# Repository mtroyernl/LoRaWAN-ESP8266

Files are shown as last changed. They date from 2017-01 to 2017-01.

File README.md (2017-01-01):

# LoRaWAN-ESP8266

Created by Mark Troyer  -  31 December 2016

Inspired by original code from Thomas Telkamp and Matthijs Kooijman  https://github.com/matthijskooijman/arduino-lmic/

## Introduction
This respository explains how to get started with LoRaWAN and The Things Network at a cost of under $50 using readily available parts.   The build consists of a LoRaWAN gateway and a simple node that senses temperature, humidity and light levels using The Things Network (thethingsnetwork.org) crowdfunded infrastructure.

The primary benefits of this build are as follows:

- Creation of an end-to-end applicaiton that leverages LoRaWAN technology and The Things Network infrastructure.
- A Bill of Materials of less that $50 for both a single-channel gateway and a node that senses temperature, humidity and light levels.
- An ideal starting point for hobbyists and professionals seeking to learn more about LoRaWAN and The Things Network.
- Uses the ESP8266 WiFi SoC (System on Chip) for primary microprocessor functions.
- Uses the Arduino IDE for simplified implementation.

In order to build the necessary two  devices, some basic soldering skills are required.  The total build time is around 3 hours.

### Limitations
*This project is built using a single channel LoRaWAN gateway. Strictly-speaking, this is out-of-spec.  LoRaWAN specifications require at minimum 3 channels.   In order to use a single channel gateway, all nodes must include software modifications to limit usage of the same single channel as the gateway.  If tested with other LoRaWAN devices, it may be that only limited packets are received by the single -channel gateway.*   

As the pricing of LoRaWAN 8 channel gateways continues to fall in 2017, it is recommended to NOT use this type of implementation in the longer term.  For basic learning and demostrations, this configuraiton may prove to be helpful to further promote the benefits of LoRaWAN in general and The Things Network specifically.  For any form of a POC (Proof of concept), a proper 8 channel gateway should be used.

## Finished Product
There are two recommended ways to build these devices:  As enclosed devices or as WeMOS D1 Mini stacks.  Building enclosed devices has the benefit of ruggedness for transportation and demonstrations.  For those looking for a rapid prototyping environment, a WeMos D1 Mini stack build is recommended.  Custom shields can be quickly created and tested using a modular hardware approach.  

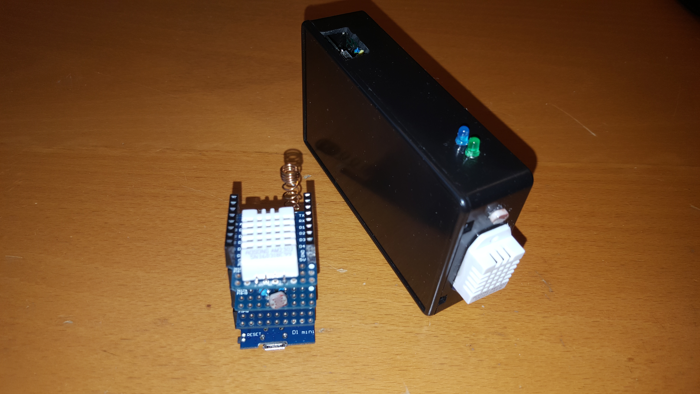
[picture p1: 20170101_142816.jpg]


Below are the internals of an enclosed device used for regular demonstrations.  A simple project box and a prototyping breadboard allow for easy and quick assembly.   Hot glue always helps as well to keep things in place!



The WeMos D1 Mini Stack device offers the ability to quickly test new hardware concepts through the use of a breadboard or custom mini shields.  Seperate shields can me mixed and matched for different experiements. 

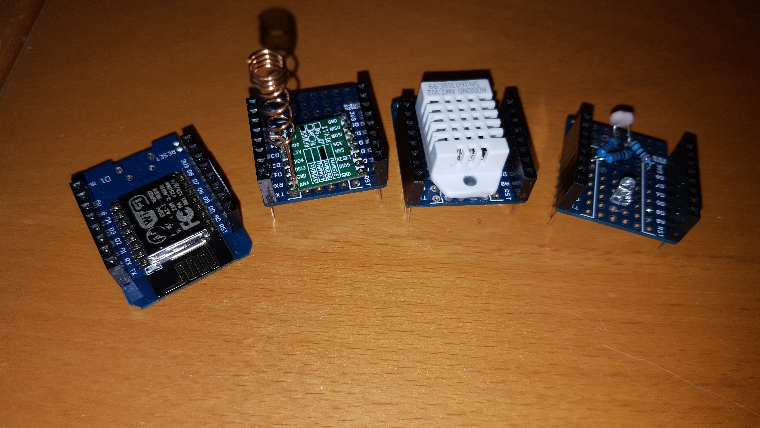
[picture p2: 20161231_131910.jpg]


## Bill of Materials
All of the parts for these builds can be ordered through local electronics suppliers or directly though Chinese suppliers with Ebay, AliExpress or others.  Below is a Bill of Materials suggested for this project:

- Wemos D1 Mini (ESP8266) $3-5 - It is recommended to order 4 or 5 of these devices for all micro processor projects.  Even for devices that do not required WiFi, the ESP8266 price point can not be beaten. The ESP8266 is also significantly faster than most Arduino boards but has fewer IO ports.
- Wemos D1 Mini Shields $2 - Order at least 10 of these for prototyping if you want to go this route.
- Prototyping breadboard $0.40 - Search for "double side prototype pcb tinned universal breadboard 5x7cm".  These are ideal and low cost prototyping breadboards for any project built in a small box.  
- RFM95 at 868MHz $9-12 - This is the basic LoRa module with a Semtech tranciever chip.  Be sure to get the version appropriate for your region (e.g. 868MHz for Europe, 915MHz for North America and Australia).  If you are in Europe, google "ebay RFM95 868" to see what's available.  Note that modules come pre-installed with the appropriate firmware for each frequency region.   Double check that you are ordering the appropriate product for your region.  It is best to order at least 3 in case one arrives DOA (Dead on Arrival) or you *fry* one accidently.
- DHT22 Temperature/Humidity Sensor $4 - Order at least 2-3 of these.
- Light-Dependent Resistor $0.50 - Normaly these come in lots of 20 or more.
- Resistors: 10K, 4K7, 2K2, 1K -  It is best to order an assortment of thru-hole resistors if you do not already have them on hand.
- 8.2cm wire antenna - I used a coil copper antenna tuned for 868MHz.  Alternatively, an 8.2cm piece of wire will also work fine.

## Hardware Schematic
The hardware schematic for the build is below.   All pins on the ESP8266 except D3/GPIO 0 are used.   9 of the 16 pins on the RFM95 are used.  Ignore the references to the RFM69 and 96.   There is still learning to be done with E-CAD !

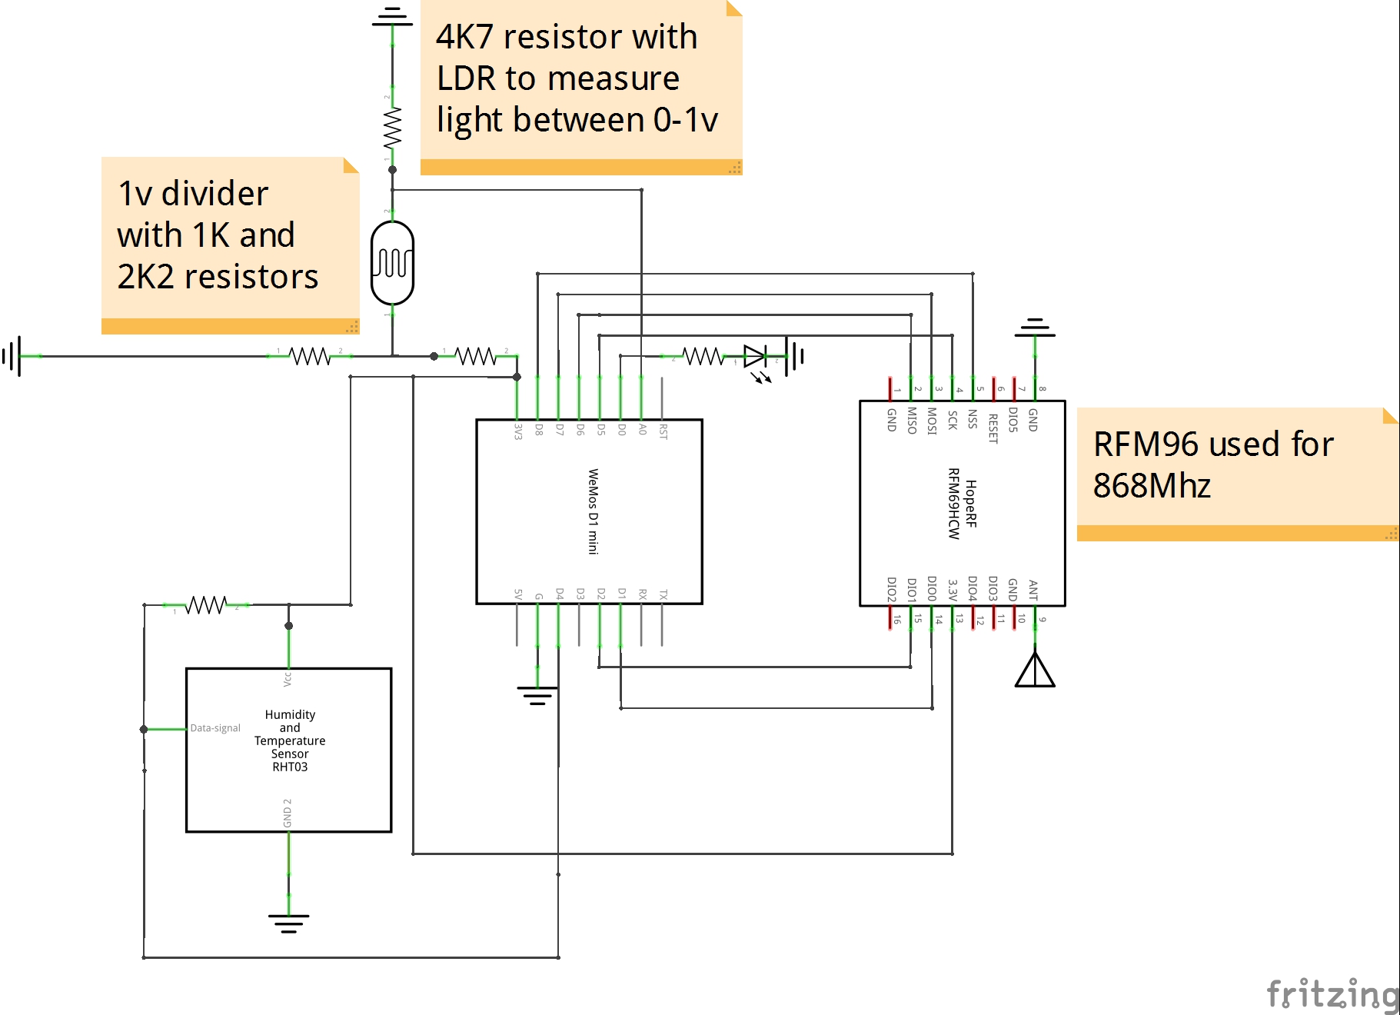
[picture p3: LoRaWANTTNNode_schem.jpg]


## Hardware build

If you are building the device using a WeMos D1 Mini stack design, it is recommended to create 3 seperate shields as follows:

- Shield for DHT22 Temperature/Humidity sensor.  These can also be purchased as finished shields or you can build your own.   If you build your own, it is important to us D4 (GPIO 02) for the signal with a 10K resistor pulled to 3.3v.   Note that D4/GPIO 02 on an ESP8266 should normally always be pulled high for normal and programming operation.   Therefore D4/GPIO 02 is the optimal pin to use for the DHT22.
- Shield for LED light and LDR.   The LED should be connected to D0 and ground.  It is very useful to have an addressable LED in firmware to indicate status of sending/receiving packets.  As the single ADC port on the ESP8266 only works between 0v and 1v, a voltage divider needs to be built using 2K2 (3.3v) and 1K (GND) resistors.  With the LDR (1v) and a 4K7 (GND) in place, a good range of digitally values between 0 and 512 will result.
- Shield for the RFM95.  This is the most complicated part of the build.  There are 9 pins on the RFM95 tranciever module that are required.  Unfortunaely, the pin holes on the RFM95 are 2mm apart where as typical prototyping breadboards are 2.54mm apart.  The result of this is that flexible core copper wire must be used to make the necessary connections to a prototyping breadboard or a header.  While not complex, assembly requires patients and forethought in terms of connections.  

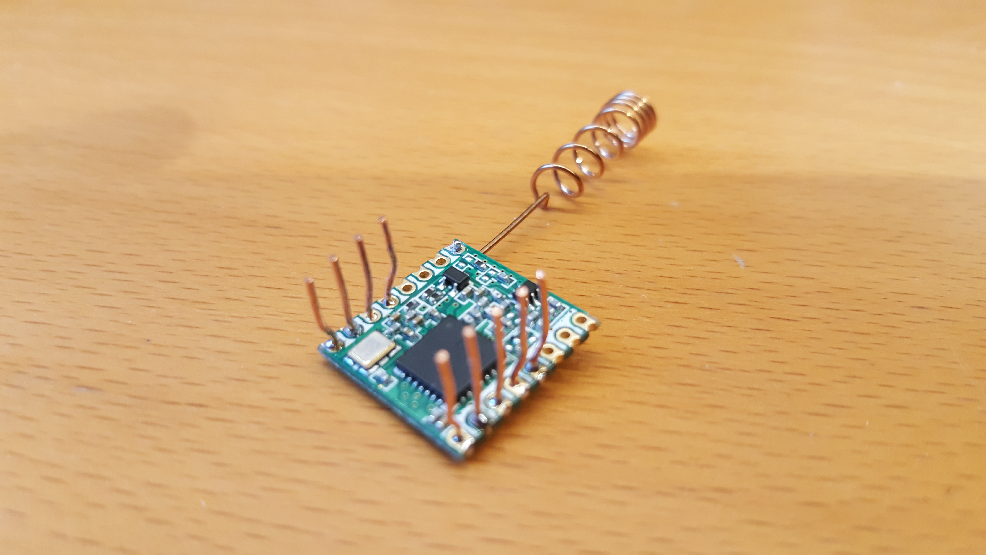
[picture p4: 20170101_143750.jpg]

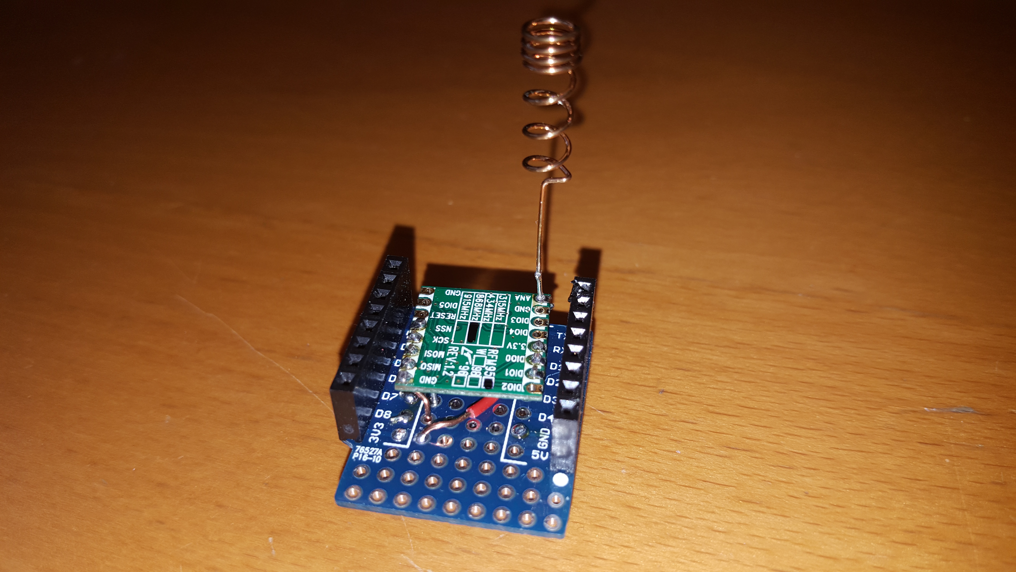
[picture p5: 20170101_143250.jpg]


Building enclosed devices can also be tricky.  Be sure to take your time and think through how connections will be made before soldering.   It is recommended to prototype assemblies first with light single solder junctions or even a bit of hot glue to make sure all will fit together.  Desolding makes a mess!   You may need that extra RFM95 or WeMos board if you did not take the necessary time to plan your build.

## Software for Node build

There will be two software builds available for nodes.  Currently only the ABP version is available.  The first works with ABP (Authentication by Personalization) using statically generated keys.   The second and recommended build works with OTAA (Over the Air Activation).  

Note that constant work is being done on the https://github.com/matthijskooijman/arduino-lmic libraries and example code.   Over time, it may make more sense to retrofit some of the sensor code back into these libraries and examples.

## Software for single-channel LoRaWAN gateway build

Code for a single channel gateway can be found at https://github.com/things4u/ESP-1ch-Gateway-v3.0.   Please be sure to re-read the Limitations section at the beginning of this document.

Note that the hardware build in this example assumes the following mappings.
```
const lmic_pinmap lmic_pins = {
    .nss = 15, // D8
    .rxtx = LMIC_UNUSED_PIN,
    .rst = LMIC_UNUSED_PIN,
    .dio = {4, 5, LMIC_UNUSED_PIN},  // D1, D2
};
```

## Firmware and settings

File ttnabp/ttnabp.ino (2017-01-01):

/*
 *  The Things Network LoRaWAN test object built for under $15.  Takes temperature, humidity, and 
 *  light sensor data and sends to the Things Network (LoRaWAN).
 *  
 *  This particular version was built to work with ABP using a single channel (868.1 mHZ) for use 
 *  with a single channel gateway for demonstrations where TTN network access may not be publically available.  
 *  8 channel functionality can be enabled in code.
 *  
 *  This was insipred from code written by Thomas Telkamp and Matthijs Kooijman  https://github.com/matthijskooijman/arduino-lmic/
 */

#include <lmic.h>           // Download from https://github.com/matthijskooijman/arduino-lmic/
#include <hal/hal.h>        // Download from https://github.com/matthijskooijman/arduino-lmic/
#include <SPI.h>
#include <ESP8266WiFi.h>
#include <DHT.h>

// ESP8266 PIN USAGE
#define LED	D0 // GPIO 16 
#define DIO0	D1 // GPIO 05
#define DIO1	D2 // GPIO 04
#define NC	D3 // GPIO 00 Reserved - Pull high to boot from SPI Flash, low to program via UART
#define DHTPIN D4 // GPIO 02 Reserved - Pulled high.   Matches as input for DHT22
#define SCK   D5 // GPIO 14
#define	MISO	D6 // GPIO 12
#define MOSI	D7 // GPIO 13
#define NSS   D8 // GPIO 15 Reserved - Pulled low to boot from SPI Flash or UART

#define DHTTYPE DHT22
DHT dht(DHTPIN, DHTTYPE, 11); // 11 works fine for ESP8266
float humidity, temperature;
int light, motion;

// LoRaWAN, DevAddr, NwkSKey, AppSKey  - Use ABP Authentication to define the values required for operation.
// See http://thethingsnetwork.org/wiki/AddressSpace
// DevAddr - Logical address created during a session.  This is not the DEV EUI which is normally a MAC layer unique address.  
//           Many LoRa radio chip implementations (e.g. RFM9X) do not have a fixed DEV EUI.
// NwkSKey - Unique shared key created by the APB registration process for the notion of a session.   This is a static key using ABP.
// AppSKey - Unique shared key created by the APB registration process for a given application.   This is a static key using ABP.

static const u4_t DEVADDR = 0x026011361;
static const PROGMEM u1_t NWKSKEY[16] = { 0x8E, 0xB0, 0x83, 0x64, 0x29, 0xBF, 0xEE, 0xFB, 0xBB, 0x3F, 0xF2, 0xBD, 0x25, 0x9F, 0xE6, 0x55 };
static const u1_t PROGMEM APPSKEY[16] = { 0x02, 0x5E, 0xA2, 0x8A, 0xBD, 0xC8, 0x45, 0xA1, 0x3D, 0x20, 0x20, 0x1E, 0x0F, 0x7F, 0xD5, 0x47 };

// These callbacks are only used in over-the-air activation, so they are
// left empty here (we cannot leave them out completely unless
// DISABLE_JOIN is set in config.h, otherwise the linker will complain).
void os_getArtEui (u1_t* buf) { }
void os_getDevEui (u1_t* buf) { }
void os_getDevKey (u1_t* buf) { }

static osjob_t sendjob;

// Schedule TX every this many seconds (might become longer due to duty
// cycle limitations).
const unsigned TX_INTERVAL = 60;

// These PIN assignments need to be adjusted for available pins on the ESP8266.  Using D8, D1, D2 works fine.
const lmic_pinmap lmic_pins = {
    .nss = 15, // D8
    .rxtx = LMIC_UNUSED_PIN,
    .rst = LMIC_UNUSED_PIN,
    .dio = {4, 5, LMIC_UNUSED_PIN},  // D1, D2
};

void blinkn (int i, int pin ) {
  int j;
  for (j=0; j < i; j++) {
    digitalWrite(pin, HIGH);
    delay (200);
    digitalWrite(pin, LOW);
    delay (200); 
  } 
}

void getReadings() {
    humidity = dht.readHumidity();
    yield();
    temperature = dht.readTemperature();
    yield();
    if (isnan(humidity) || isnan(temperature)) {
      Serial.println("Failed to read from DHT sensor!");
      humidity = 0;
      temperature = 0;
    }
    yield();
    light = analogRead(A0);
    yield();
}

void do_send(osjob_t* j);
void onEvent (ev_t ev) {
    Serial.print(os_getTime());
    Serial.print(": ");
    switch(ev) {
        case EV_SCAN_TIMEOUT:
            Serial.println(F("EV_SCAN_TIMEOUT"));
            break;
        case EV_BEACON_FOUND:
            Serial.println(F("EV_BEACON_FOUND"));
            break;
        case EV_BEACON_MISSED:
            Serial.println(F("EV_BEACON_MISSED"));
            break;
        case EV_BEACON_TRACKED:
            Serial.println(F("EV_BEACON_TRACKED"));
            break;
        case EV_JOINING:
            Serial.println(F("EV_JOINING"));
            break;
        case EV_JOINED:
            Serial.println(F("EV_JOINED"));
            break;
        case EV_RFU1:
            Serial.println(F("EV_RFU1"));
            break;
        case EV_JOIN_FAILED:
            Serial.println(F("EV_JOIN_FAILED"));
            break;
        case EV_REJOIN_FAILED:
            Serial.println(F("EV_REJOIN_FAILED"));
            break;
            break;
        case EV_TXCOMPLETE:
            blinkn (1,LED); // Blink the LED once to indicate that this callback was received.
            Serial.println(F("EV_TXCOMPLETE (includes waiting for RX windows)"));
            if (LMIC.txrxFlags & TXRX_ACK)
              Serial.println(F("Received ack"));
            if (LMIC.dataLen) {
              blinkn (LMIC.dataLen,LED); // Blink the LED to show byte size of data received.
              Serial.print(F("Received "));
              Serial.print(LMIC.dataLen);
              Serial.println(F(" bytes of payload"));
            }
            // Schedule next transmission
            os_setTimedCallback(&sendjob, os_getTime()+sec2osticks(TX_INTERVAL), do_send);
            break;
        case EV_LOST_TSYNC:
            Serial.println(F("EV_LOST_TSYNC"));
            break;
        case EV_RESET:
            Serial.println(F("EV_RESET"));
            break;
        case EV_RXCOMPLETE:
            // data received in ping slot
            Serial.println(F("EV_RXCOMPLETE"));
            break;
        case EV_LINK_DEAD:
            Serial.println(F("EV_LINK_DEAD"));
            break;
        case EV_LINK_ALIVE:
            Serial.println(F("EV_LINK_ALIVE"));
            break;
         default:
            Serial.println(F("Unknown event"));
            break;
    }
}

void do_send(osjob_t* j){
    blinkn (2,LED); // Blink the LED twice to indicate that we will be sending data shortly
    getReadings();

    int16_t temperatureb2 = (int16_t)(temperature * 100);
    int16_t humidityb2 = (int16_t)(humidity * 100);
    int16_t lightb2 = (int16_t)(light * 100);
    
    byte data[7];
    data[0] = temperatureb2 >> 8;
    data[1] = temperatureb2 & 0xFF;
    data[2] = humidityb2 >> 8;
    data[3] = humidityb2 & 0xFF;
    data[4] = lightb2 >> 8;
    data[5] = lightb2 & 0xFF;
    
    // Check if there is not a current TX/RX job running
    if (LMIC.opmode & OP_TXRXPEND) {
        Serial.println(F("OP_TXRXPEND, not sending"));
    } else {
        // Prepare upstream data transmission at the next possible time.
        LMIC_setTxData2(1, data, sizeof(data)-1, 0);
        Serial.println(F("Packet queued"));
    }
    // Next TX is scheduled after TX_COMPLETE event.
}

void setup() {
    WiFi.forceSleepBegin(); // turn off ESP8266 RF
    delay(1);               // give RF section time to shutdown
  
    Serial.begin(115200);
    Serial.println(F("Starting"));

    // Start up DHT sensor, wait and take an initial reading
    dht.begin();            
    delay (200);
    getReadings();
    
    pinMode(LED, OUTPUT);
    
    #ifdef VCC_ENABLE
    // For Pinoccio Scout boards
    pinMode(VCC_ENABLE, OUTPUT);
    digitalWrite(VCC_ENABLE, HIGH);
    delay(1000);
    #endif

    // LMIC init
    os_init();
    yield();
    // Reset the MAC state. Session and pending data transfers will be discarded.
    LMIC_reset();
    yield();

    // Set static session parameters. Instead of dynamically establishing a session
    // by joining the network, precomputed session parameters are be provided.
    #ifdef PROGMEM
    // On AVR, these values are stored in flash and only copied to RAM
    // once. Copy them to a temporary buffer here, LMIC_setSession will
    // copy them into a buffer of its own again.
    uint8_t appskey[sizeof(APPSKEY)];
    uint8_t nwkskey[sizeof(NWKSKEY)];
    memcpy_P(appskey, APPSKEY, sizeof(APPSKEY));
    memcpy_P(nwkskey, NWKSKEY, sizeof(NWKSKEY));
    LMIC_setSession (0x1, DEVADDR, nwkskey, appskey);
    #else
    // If not running an AVR with PROGMEM, just use the arrays directly 
    LMIC_setSession (0x1, DEVADDR, NWKSKEY, APPSKEY);
    #endif

    // Set up the channels used by the Things Network, which corresponds
    // to the defaults of most gateways. Without this, only three base
    // channels from the LoRaWAN specification are used, which certainly
    // works, so it is good for debugging, but can overload those
    // frequencies, so be sure to configure the full frequency range of
    // your network here (unless your network autoconfigures them).
    // Setting up channels should happen after LMIC_setSession, as that
    // configures the minimal channel set.

    //Limit this to 868100000 for single channel use

    LMIC_setupChannel(0, 868100000, DR_RANGE_MAP(DR_SF12, DR_SF7),  BAND_CENTI);      // g-band
    LMIC_setupChannel(1, 868100000, DR_RANGE_MAP(DR_SF12, DR_SF7),  BAND_CENTI);      // g-band
    LMIC_setupChannel(2, 868100000, DR_RANGE_MAP(DR_SF12, DR_SF7),  BAND_CENTI);      // g-band
 
    // Use with multiple channels
    /*
    LMIC_setupChannel(0, 868100000, DR_RANGE_MAP(DR_SF12, DR_SF7),  BAND_CENTI);      // g-band
    LMIC_setupChannel(1, 868300000, DR_RANGE_MAP(DR_SF12, DR_SF7B), BAND_CENTI);      // g-band
    LMIC_setupChannel(2, 868500000, DR_RANGE_MAP(DR_SF12, DR_SF7),  BAND_CENTI);      // g-band
    LMIC_setupChannel(3, 867100000, DR_RANGE_MAP(DR_SF12, DR_SF7),  BAND_CENTI);      // g-band
    LMIC_setupChannel(4, 867300000, DR_RANGE_MAP(DR_SF12, DR_SF7),  BAND_CENTI);      // g-band
    LMIC_setupChannel(5, 867500000, DR_RANGE_MAP(DR_SF12, DR_SF7),  BAND_CENTI);      // g-band
    LMIC_setupChannel(6, 867700000, DR_RANGE_MAP(DR_SF12, DR_SF7),  BAND_CENTI);      // g-band
    LMIC_setupChannel(7, 867900000, DR_RANGE_MAP(DR_SF12, DR_SF7),  BAND_CENTI);      // g-band
    LMIC_setupChannel(8, 868800000, DR_RANGE_MAP(DR_FSK,  DR_FSK),  BAND_MILLI);     // g2-band
 */
    // TTN defines an additional channel at 869.525Mhz using SF9 for class B
    // devices' ping slots. LMIC does not have an easy way to define set this
    // frequency and support for class B is spotty and untested, so this
    // frequency is not configured here.

    // Disable link check validation
    LMIC_setLinkCheckMode(0);

    // Set data rate and transmit power (note: txpow seems to be ignored by the library)
    LMIC_setDrTxpow(DR_SF7,14);

    // Start job
    do_send(&sendjob);
}

void loop() {
    os_runloop_once();
}
